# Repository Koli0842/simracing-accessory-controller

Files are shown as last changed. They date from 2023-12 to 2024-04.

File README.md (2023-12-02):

# Simracing Accessory Controller

This project is started off as a homemade analog handbrake made from spare parts of a 20 years old plastic steering wheel pedals.

The project is extremely simple based on the Library https://github.com/MHeironimus/ArduinoJoystickLibrary, I use an Arduino Pro Micro in my instance.

Since my G29 Shifter is acting up, requiring a re-plug it to the wheel base each powerup, which is very inconvinient with a hard-mount, so I am considering incorporating code from https://github.com/JRomainG/Driving-Force-Shifter-USB-Adapter to have it all in one place.

Once I get to upgrade my rig, I will probably populate the rest of my IO pins with extra buttons and switches on a button board, complete with 3D printed parts.

I might add stl-s for 3d printing a really cheap analogue handbrake version too, my current one is partially made of metal.

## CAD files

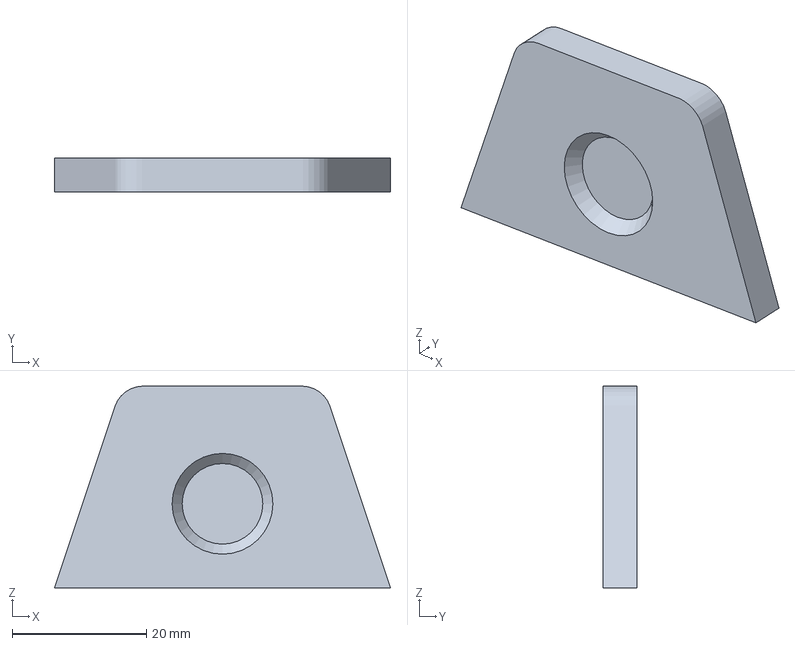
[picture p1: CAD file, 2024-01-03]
handbrake-assets/simracing-handbrake-v2-clamp-shelf.3mf
50.0 x 5.00 x 30.0 mm

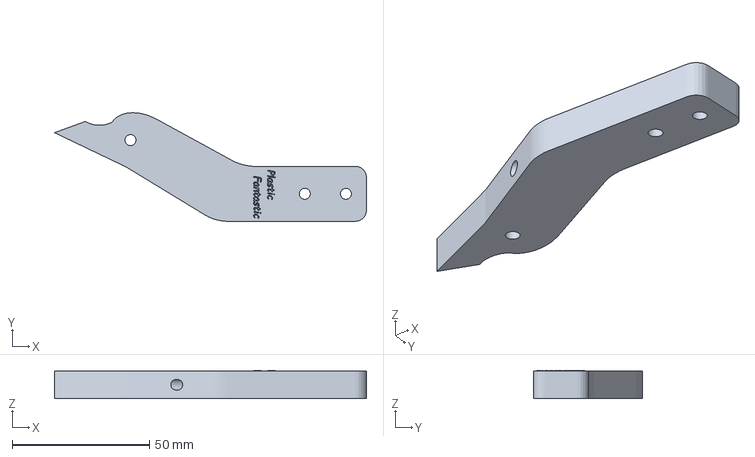
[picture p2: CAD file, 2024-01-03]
handbrake-assets/simracing-handbrake-v2-actuator.3mf
113.6 x 39.5 x 10.2 mm

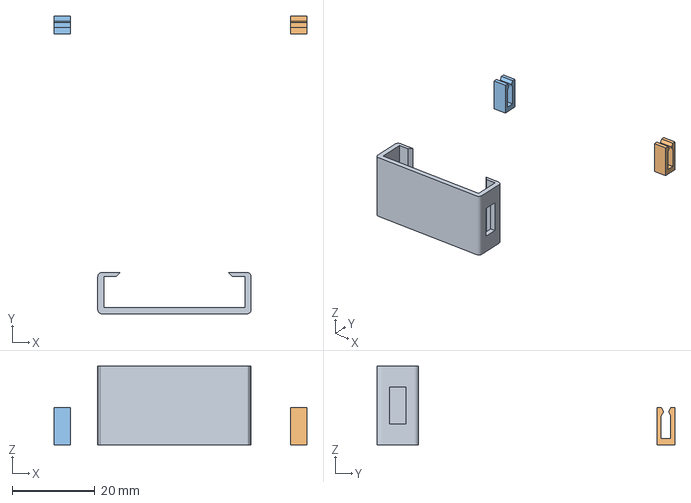
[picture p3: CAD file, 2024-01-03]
handbrake-assets/simracing-handbrake-v2-arduino-cage.3mf
61.0 x 71.8 x 19.0 mm
simracing-handbrake-v2-arduino-cage.stl
simracing-handbrake-v2-cable-clamp.stl x 2

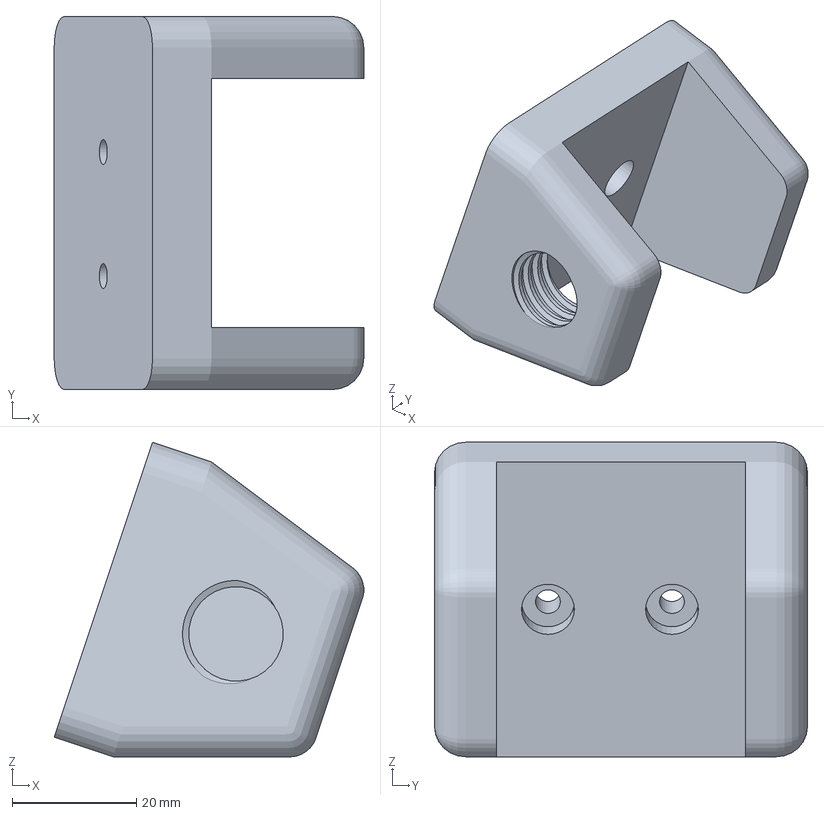
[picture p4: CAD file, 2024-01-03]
handbrake-assets/simracing-handbrake-v2-clamp-body.3mf
49.8 x 60.0 x 50.6 mm

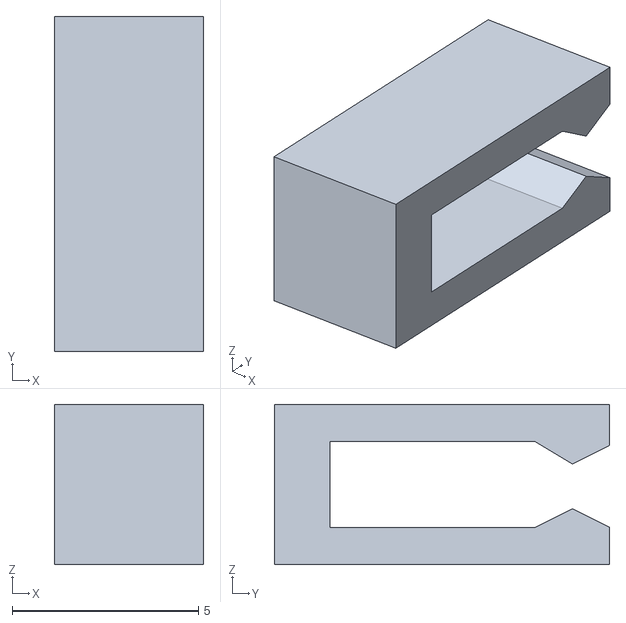
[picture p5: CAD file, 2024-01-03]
handbrake-assets/simracing-handbrake-v2-cable-clamp.stl
4.00 x 9.00 x 4.30

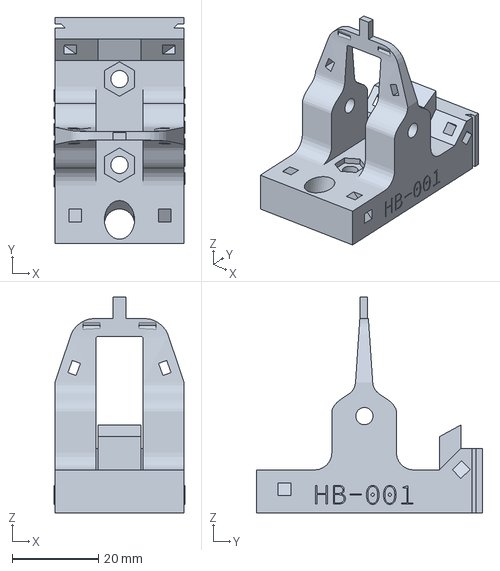
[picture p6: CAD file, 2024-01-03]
handbrake-assets/simracing-handbrake-v2-body.3mf
30.4 x 52.5 x 50.2 mm

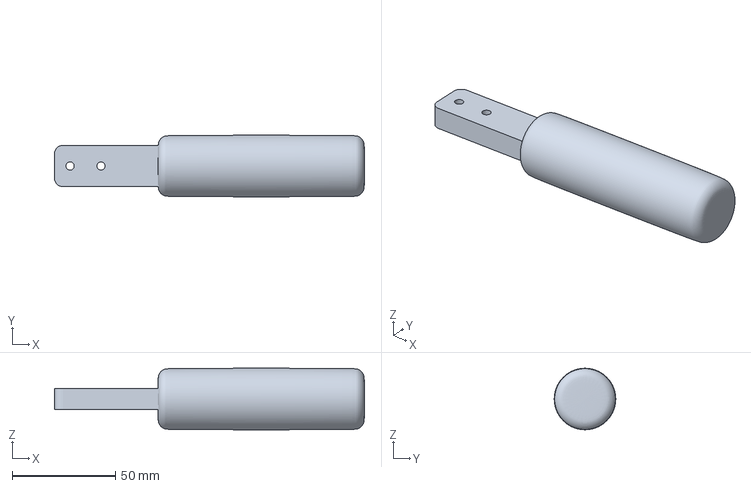
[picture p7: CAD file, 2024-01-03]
handbrake-assets/simracing-handbrake-v2-grip.3mf
150.0 x 29.8 x 29.8 mm

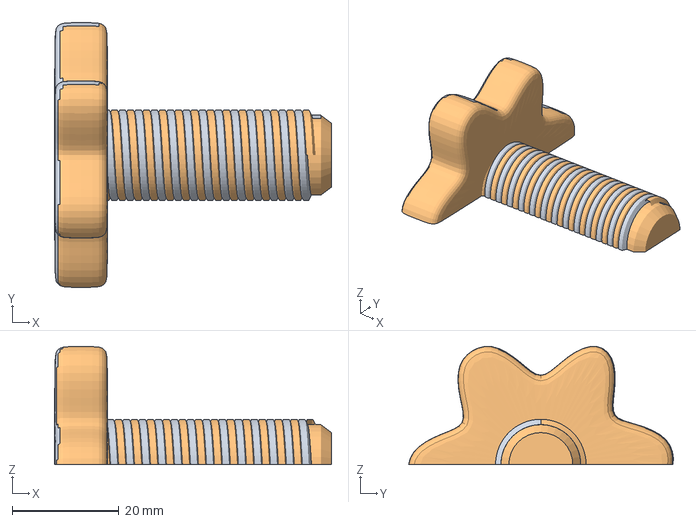
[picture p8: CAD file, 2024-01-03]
handbrake-assets/simracing-handbrake-v2-clamp-tightener.3mf
52.0 x 49.7 x 22.2 mm
simracing-handbrake-v2-clamp-tightener A.stl
simracing-handbrake-v2-clamp-tightener B.stl

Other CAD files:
handbrake-assets/simracing-handbrake-v2-actuator.stl
handbrake-assets/simracing-handbrake-v2-arduino-cage.stl
handbrake-assets/simracing-handbrake-v2-body.stl
handbrake-assets/simracing-handbrake-v2-clamp-body.stl
handbrake-assets/simracing-handbrake-v2-clamp-shelf.stl
handbrake-assets/simracing-handbrake-v2-clamp-tightener.stl
handbrake-assets/simracing-handbrake-v2-grip.stl

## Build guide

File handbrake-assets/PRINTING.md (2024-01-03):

I designed a 3D printed very minimal handbrake to serve as an entry point one can make with a 3D Printer and basic soldering skills easily. It has a small footprint, a desk clamp, and a hall effect sensor. I have a mostly stock Ender 3. It totals at about ~100g filament.

### Bill of Materials:

| Amount | Item | Approx Price 
|---|---|---
| ~110g | PLA filament of your choice | 3€
| 4 pcs | 30mm M4 screw, cut 2 of them| 0.10€ / pc
| 2 pcs | 40mm M4 screw | 0.10€ / pc
| 6 pcs | M4 nut | 0.10€ / p
| 1 pcs | Honeywell SS49E | 1€
| 1 pcs | Magnet (3x12mm AlNiCo500) | 1€
| 1 pcs | Arduino Pro Micro (Clone) | 10€
| 3 x 100mm| Wire (ended up w/ LED conn) | 0.25€ / meter
|||
|Total||~ 16.50€|

### Printing

I generally print with 3 perimeters, 4 bottom, 3 top, 18% gyroid infill

#### Settings and parts info:

##### Desk Clamp Body
- Printed on the slanted side to avoid layer separation as the weakest point
- 42% gyroid infill
- Used 35g PLA

##### Desk Clamp Shelf
- Printed on narrow side to avoid layer separation as the weakest point
- Used 4.3g PLA

##### Desk Clamp Tightener
- Printed with cut in half & hot glued together
- 0 bottom perimeter to allow gluing
- 18% gyroid infill
- Used 12g PLA

##### Handbrake Body
- Defaults, hopefully layer separation won't be an issue on this piece
- Used 12g PLA

##### Handbrake Actuator
- Defaults
- Used 11g PLA

##### Handbrake Grip
- auto support under 30°
- 13% gyroid infill
- Used 29g PLA

##### Arduino Cage
- Defaults
- Used 2g PLA

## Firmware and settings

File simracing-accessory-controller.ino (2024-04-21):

#include "Joystick.h"

#define HANDBRAKE true
#define SHIFTER true
#define DEBUG false
#define DEBUG_HALL false
#define DEBUG_SHIFTER false

#define HANDBRAKE_AXIS_MAX 1023
#define HANDBRAKE_AXIS_TOP_TRESHOLD 700
#define HANDBRAKE_AXIS_BOTTOM_TRESHOLD 550
#define HANDBRAKE_POLARITY true
#define HANDBRAKE_GAMMA 1.6

#define SHIFTER_AXIS_LEFT 400
#define SHIFTER_AXIS_RIGHT 650
#define SHIFTER_AXIS_TOP 800
#define SHIFTER_AXIS_BOTTOM 200

#define JOYSTICK_BUTTON_GR 6
#define JOYSTICK_BUTTON_G1 0
#define JOYSTICK_BUTTON_G2 1
#define JOYSTICK_BUTTON_G3 2
#define JOYSTICK_BUTTON_G4 3
#define JOYSTICK_BUTTON_G5 4
#define JOYSTICK_BUTTON_G6 5

#define PIN_HANDBRAKE A0
#define PIN_G29_SHIFTER_X A2
#define PIN_G29_SHIFTER_Y A3
#define PIN_G29_DOWN 14

enum Gear {
    FIRST, SECOND, THIRD, FOURTH, FIFTH, SIXTH, REVERSE, NEUTRAL
};

Gear SELECTED_GEAR = Gear::NEUTRAL;

Joystick_ Joystick(JOYSTICK_DEFAULT_REPORT_ID, JOYSTICK_TYPE_JOYSTICK, 7, 0,
        false, false, false,
        true, false, false,
        false, false, false, false, false);

void setup() {
    pinMode(PIN_HANDBRAKE, INPUT_PULLUP);
    pinMode(PIN_G29_SHIFTER_X, INPUT_PULLUP);
    pinMode(PIN_G29_SHIFTER_Y, INPUT_PULLUP);
    pinMode(PIN_G29_DOWN, INPUT);
    Serial.begin(9600);
    Joystick.begin();
    Joystick.setRxAxisRange(0, HANDBRAKE_AXIS_MAX);
}

void loop() {
    int normalizedReading, handbrakeValue, shifterHorizontalValue, shifterVerticalValue;
    bool shifterPressedDown;
    Gear gear;
    if (HANDBRAKE || DEBUG) {
        normalizedReading = normalizeReading(analogRead(PIN_HANDBRAKE));
        handbrakeValue = applyGammaFilter(normalizedReading);
        Joystick.setRxAxis(handbrakeValue);
    }

    if (SHIFTER || DEBUG) {
        shifterHorizontalValue = analogRead(PIN_G29_SHIFTER_X);
        shifterVerticalValue = analogRead(PIN_G29_SHIFTER_Y);
        shifterPressedDown = digitalRead(PIN_G29_DOWN);
        gear = !shifterPressedDown ?
            findGear(shifterHorizontalValue, shifterVerticalValue) :
            findGearDown(shifterHorizontalValue, shifterVerticalValue);
        updateShifter(gear);
    }

    
    if (DEBUG) {
        char buffer[100];
        sprintf(buffer, "Handbrake [ %d ] Shifter [ %d | X %d Y %d PRESSED %x ]",
            handbrakeValue, gear, shifterHorizontalValue, shifterVerticalValue, shifterPressedDown);
        Serial.println(buffer);
    }
}

int applyGammaFilter(const int& reading) {
    return pow(reading / (double)HANDBRAKE_AXIS_MAX, 1.0 / HANDBRAKE_GAMMA) * HANDBRAKE_AXIS_MAX;
}

int normalizeReading(const int& reading) {
    if (DEBUG_HALL) {
        char buffer[100];
        sprintf(buffer, "Handbrake [ %d ]", reading);
        Serial.println(buffer);
    }
    int polarizedValue;
    if (HANDBRAKE_POLARITY) {
        polarizedValue = constrain(reading, HANDBRAKE_AXIS_BOTTOM_TRESHOLD, HANDBRAKE_AXIS_TOP_TRESHOLD);
    } else {
        polarizedValue = constrain(HANDBRAKE_AXIS_MAX - reading, HANDBRAKE_AXIS_MAX - HANDBRAKE_AXIS_TOP_TRESHOLD, HANDBRAKE_AXIS_MAX - HANDBRAKE_AXIS_BOTTOM_TRESHOLD);
    }
    return map(polarizedValue, HANDBRAKE_AXIS_BOTTOM_TRESHOLD, HANDBRAKE_AXIS_TOP_TRESHOLD, 0, HANDBRAKE_AXIS_MAX);
}

void setHandbrakeButton(const int& axisValue) {
    if (axisValue > HANDBRAKE_AXIS_MAX/2) {
        Joystick.pressButton(0);
    } else {
        Joystick.releaseButton(0);
    }
}

void updateShifter(const Gear& gear) {
    if (gear == SELECTED_GEAR) return;
    if (gear != Gear::NEUTRAL && SELECTED_GEAR != Gear::NEUTRAL) return; // Only allow gearshifts through neutral, fix twitchy sensors & overlap between gears

    if (DEBUG_SHIFTER) {
        char buffer[100];
        sprintf(buffer, "Shifter [ %d ] -> [ %d ]", SELECTED_GEAR, gear);
        Serial.println(buffer);
    }
    
    switch (gear) {
    case Gear::FIRST:
        Joystick.pressButton(JOYSTICK_BUTTON_G1);
        break;
    case Gear::SECOND:
        Joystick.pressButton(JOYSTICK_BUTTON_G2);
        break;
    case Gear::THIRD:
        Joystick.pressButton(JOYSTICK_BUTTON_G3);
        break;
    case Gear::FOURTH:
        Joystick.pressButton(JOYSTICK_BUTTON_G4);
        break;
    case Gear::FIFTH:
        Joystick.pressButton(JOYSTICK_BUTTON_G5);
        break;
    case Gear::SIXTH:
        Joystick.pressButton(JOYSTICK_BUTTON_G6);
        break;
    case Gear::REVERSE:
        Joystick.pressButton(JOYSTICK_BUTTON_GR);
        break;
    case Gear::NEUTRAL:
        Joystick.releaseButton(SELECTED_GEAR);
        break;
    }
    SELECTED_GEAR = gear;
}

Gear findGear(const int& x, const int& y) {
    if (y > SHIFTER_AXIS_TOP) {
    if (x < SHIFTER_AXIS_LEFT) {
            return Gear::FIRST;
        } else if (x > SHIFTER_AXIS_RIGHT) {
            return Gear::FIFTH;
        } else {
            return Gear::THIRD;
        }
        } else if (y < SHIFTER_AXIS_BOTTOM) {
        if (x < SHIFTER_AXIS_LEFT) {
            return Gear::SECOND;
    } else if (x > SHIFTER_AXIS_RIGHT) {
            return Gear::SIXTH;
    } else {
            return Gear::FOURTH;
        }
    }
    return Gear::NEUTRAL;
}

Gear findGearDown(const int& x, const int& y) {
    if (x > SHIFTER_AXIS_RIGHT) {
        if (y < SHIFTER_AXIS_BOTTOM) {
            return Gear::REVERSE;
        }
    }
    return Gear::NEUTRAL;
}

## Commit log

2023-12-24 Add gamma filtering
2024-01-03 Add printable handbrake assets and support
    [simracing-handbrake-v2-actuator.3mf, simracing-handbrake-v2-actuator.stl, simracing-handbrake-v2-arduino-cage.3mf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]
2024-04-21 Improve G29 shifter support, handle twitchy sensors
    [simracing-accessory-controller.ino]
